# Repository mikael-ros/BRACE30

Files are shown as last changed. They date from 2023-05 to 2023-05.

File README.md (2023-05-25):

# BRACE30

Excuse the assorted keycaps :o (I did not have all of them)
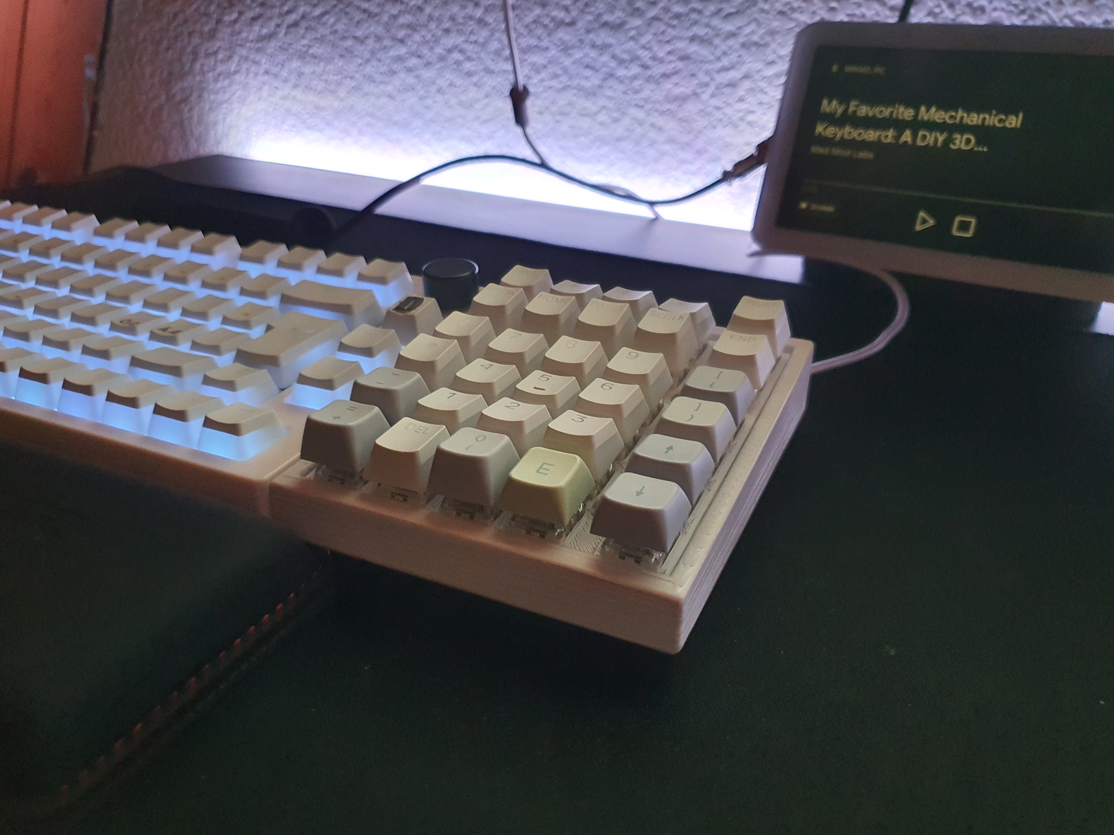
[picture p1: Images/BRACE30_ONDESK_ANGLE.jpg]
BRACE30


A 30% extended numpad, running on the tiny Adafruit QT PY 2040. 

I only designed this to get a shortcut for {}, [], and / - hence "BRACE"

My first handwired keyboard, and one of my first CAD designs overall.

---

## Parts used
* eSun PLA+ White, for case and plate
* Adafruit QT PY RP2040, for controlling keys
* Colored cables for identification
* "1N4148 DO-35 75V 300mA" diodes
* Kailh BOX White switches
* Mainly Steelseries Pudding keycaps
* 5 mm long M3 screws, specifically harvested from an old microwave at some point

## Features
* KMK (all though, this depends on your microcontroller)
* 30 keys
* Matched to the dimensions of the Epomaker TH80 Pro
    * Which means a curved side profile
* Nordic layout support (by way of key combos in KMK)
* Screw threads built in, if you print at the right settings

## Design process
1. [Keyboard layout editor](http://www.keyboard-layout-editor.com/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) was used to make the layout, and export it
2. [ai03](https://kbplate.ai03.com/) was then used to export the plate CAD files
3. Measurments were taken of the Epomaker and the parts
4. The model was sketched up in Fusion 360
### Pitfalls
* During the project, I first tried to print with PETG, which was a nightmare
* I had to cut the USB C port a little, to allow room for the USB C cable

## 3D printing settings
> I used a Sovol SV06 to print these

### Plate
* See CURA profile in CAD files, but change:
    * 50% infill, Cross 3D
    * Print upside down

### Case
* See CURA profile in CAD files

## Construction
BRACE30 plate

1. I first soldered all the rows, with the diode legs, then all the columns, see [Mad Mod Labs](https://www.youtube.com/watch?v=iv__343ZwE0&t=1068s)
2. I then soldered each column and row to a GPIO pin each

BRACE30 cables

BRACE30 soldered

3. Extended the hole for the USB C cable (check "Known Issues")

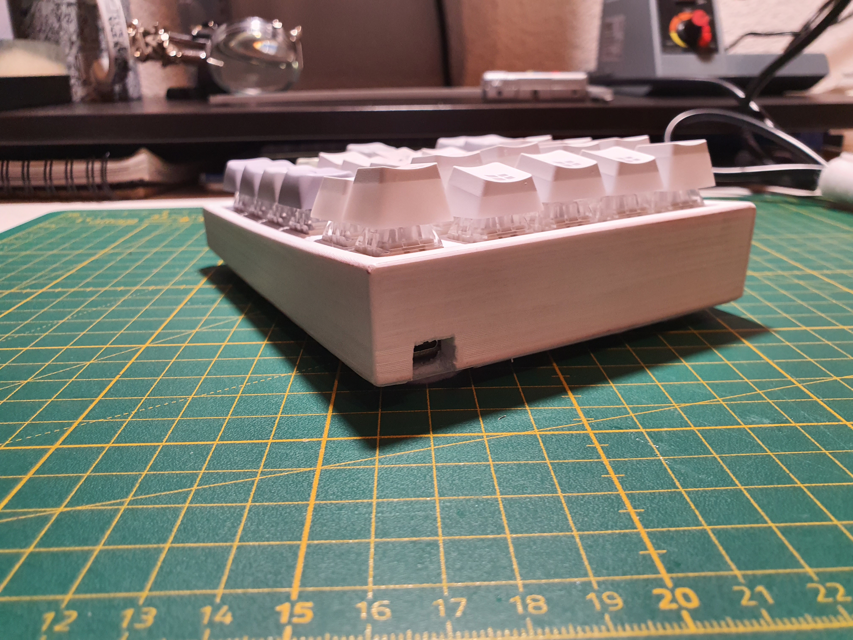
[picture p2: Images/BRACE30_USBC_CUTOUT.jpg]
BRACE30 cutout


4. Downloaded and installed CircuitPython onto the board, and then [KMK](https://github.com/KMKfw/kmk_firmware)
5. Sanded the sides until smooth
6. Screwed together the case and glued the microcontroller to the port section

BRACE30 switchplate
---

## Known issues
- [ ] USB C port is not flush, you need to cut into the PLA or redesign the case
- [ ] Plate height is higher than TH80, which was not the plan, but it does not affect anything
- [ ] Tolerances on plate are a tad too loose, which could be fixed by subtracting about 0.1 mm from the holes - this means switches easily pop out currently (unless you decide to hot glue them)
- [ ] Microcontroller does not fit into slot made for it, needs an additional tolerance of about 0.2-0.3 mm
- [x] KMK is for some reason flipped
- [ ] Work around for Nordic keys

## Future plans
- [ ] Print a new case
- [ ] Make firmware more advanced
- [ ] Get uniform keycaps

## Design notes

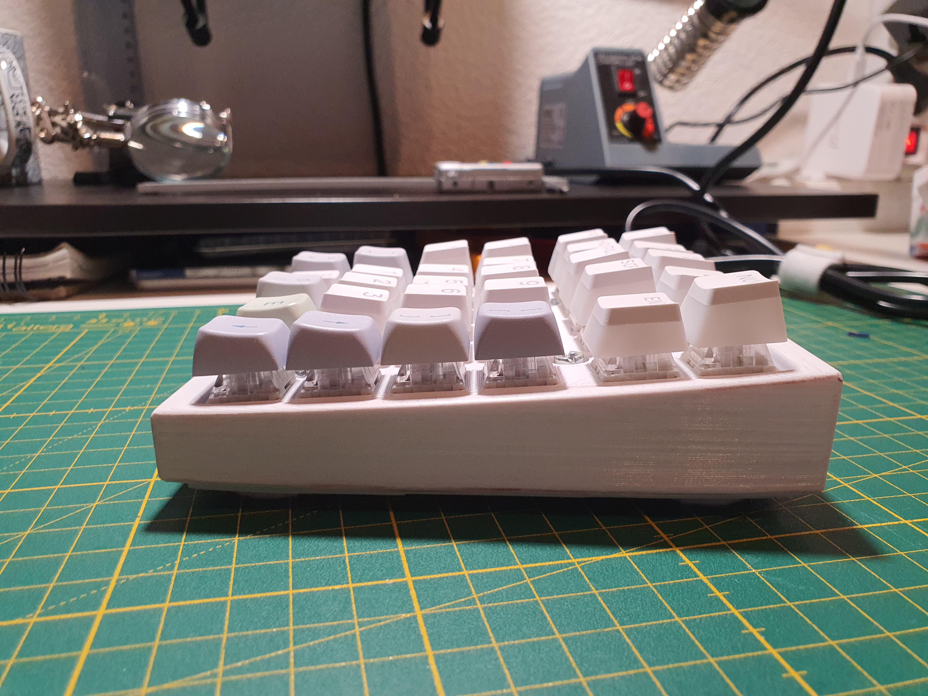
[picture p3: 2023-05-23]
Images/BRACE30_SIDE.jpg

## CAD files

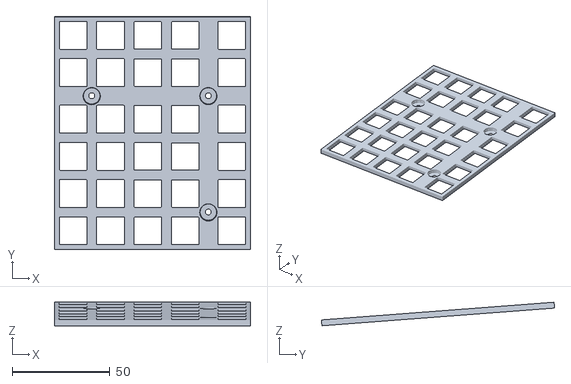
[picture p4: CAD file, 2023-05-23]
CAD files/Plate.stl
100.0 x 118.9 x 12.0

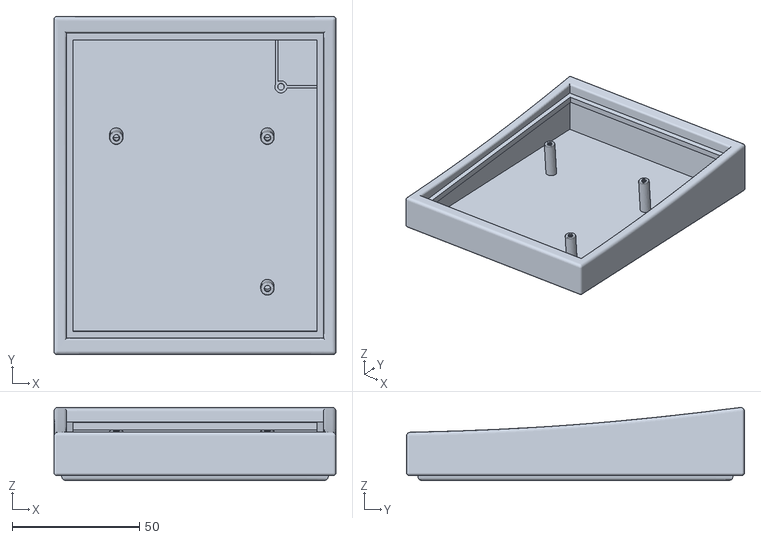
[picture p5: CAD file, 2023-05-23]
CAD files/Case (walls).stl
111.0 x 133.1 x 28.8

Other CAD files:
CAD files/BRACE30.f3d

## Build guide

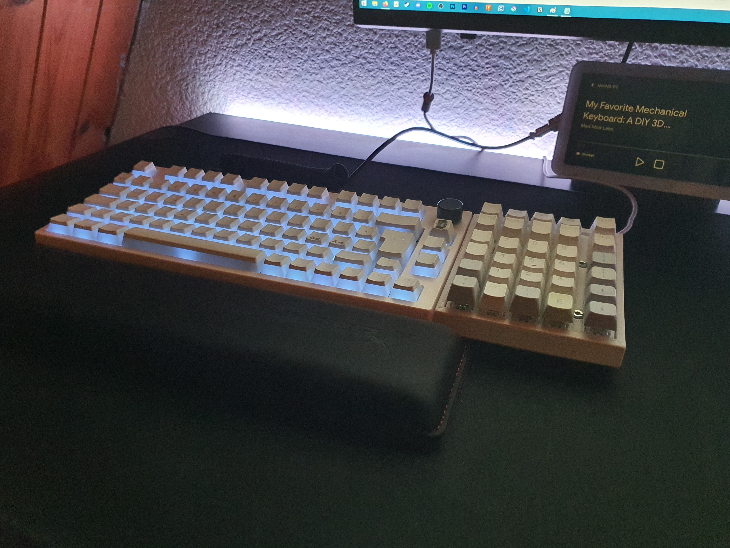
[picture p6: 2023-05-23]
Images/BRACE30_ONDESK_SETUP.jpg

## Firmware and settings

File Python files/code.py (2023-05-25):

print("Starting")

import board

from kmk.kmk_keyboard import KMKKeyboard
from kmk.keys import KC
from kmk.extensions.international import International
from kmk.extensions.media_keys import MediaKeys
from kmk.keys import make_key
from kmk.modules.combos import Combos, Chord, Sequence
from kmk.modules.layers import Layers
from kmk.scanners import DiodeOrientation

keyboard = KMKKeyboard()
keyboard.extensions.append(MediaKeys())
keyboard.extensions.append(International())
keyboard.modules.append(Layers())
combos = Combos()
keyboard.modules.append(combos)

keyboard.col_pins = (board.A1, board.A3, board.SDA, board.A2, board.SCL,)
keyboard.row_pins = (board.SCK, board.MISO, board.A0, board.TX, board.RX, board.MOSI)



keyboard.diode_orientation = DiodeOrientation.COL2ROW

"""
The below was just an input test, to se if all buttons were working.
Layer 1:
a b  c  d  OK
a OK OK OK OK
/ 7  8  9  {
* 4  5  6  }
- 1  2  3  [
+ OK 0  =  ]
"""
"""
The following is the layout I soldered, though I do not recommend it for organizing
#        1  2  3   4    5
  PIN   A1 A3 SDA A2   SCL
1 SCK   [] [] []  []   []
2 MISO  [] [] []  []   []

3 A0    [] [] []  []   []
4 TX    [] [] []  []   []
5 RX    [] [] []  []   []
6 MOSI  [] [] []  []   []
"""

"""
               NUMPAD LAYER
#        1      2      3       4       5
  PIN   A1     A3     SDA     A2      SCL
1 SCK   [INS]  [COPY] [PASTE] [CUT]   [NUM]
2 MISO  [LYR1] [<-]   [||]    [->]    [<--]

3 A0    [/]    [7]    [8]     [9]     [{]
4 TX    [*]    [4]    [5]     [6]     [}]
5 RX    [-]    [1]    [2]     [3]     [[]
6 MOSI  [+]    [DEL]  [0]     [=]     []]
"""

"""
                ARROW LAYER
#        1       2      3       4      5
  PIN   A1      A3     SDA     A2     SCL
1 SCK   [ESC]   [F1]   [F2]    [F3]   [F4]
2 MISO  [LYR1]  [1]    [2]     [3]    [4]

3 A0    [TAB]   [Q]    [W]     [R]    [A]
4 TX    [C]     [A]    [S]     [D]    [A]
5 RX    [SHIFT] [T]    [B]     [E]    [A]
6 MOSI  [Z]     [CTRL] [SPACE] [A]    [A]
"""

keyboard.keymap = [
    [
        KC.INS,           KC.LCTRL(KC.C), KC.LCTRL(KC.V), KC.LCTRL(KC.X),       KC.NLCK,
        KC.TO(1),         KC.MPRV,        KC.MPLY,        KC.MNXT,              KC.BSPACE,

        KC.LSHIFT(KC.N7), KC.P7,          KC.P8,          KC.P9,                KC.RALT(KC.N7),
        KC.PAST,          KC.P4,          KC.P5,          KC.P6,                KC.RALT(KC.N0),
        KC.PMNS,          KC.P1,          KC.P2,          KC.P3,                KC.RALT(KC.N8),
        KC.PPLS,          KC.DEL,         KC.P0,          KC.LSHIFT(KC.N0),     KC.RALT(KC.N9),
    ],
    [
        KC.ESC,    KC.F1,    KC.F2,    KC.F3,   KC.F4,
        KC.TO(0),  KC.N1,    KC.N2,    KC.N3,   KC.N4,

        KC.TAB,    KC.Q,     KC.W,     KC.R,    KC.A,
        KC.C,      KC.A,     KC.S,     KC.D,    KC.A,
        KC.LSHIFT, KC.T,     KC.B,     KC.E,    KC.A,
        KC.Z,      KC.LCTRL, KC.SPACE, KC.A,    KC.A,
    ]
]
if __name__ == '__main__':
    keyboard.go()

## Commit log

2023-05-23 CAD files added, readme added
    [BRACE30.f3d, Case (walls).stl, Plate.stl]
2023-05-25 Layout updated, layers added, flip issue fixed
    [code.py]
